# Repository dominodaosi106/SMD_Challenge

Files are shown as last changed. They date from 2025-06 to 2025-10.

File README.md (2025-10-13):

# SMD Challenge Badge

SMD Challenge Badge

# SMD_Challenge

このプロジェクトは、aspro648の[Attiny85Challenge](https://github.com/aspro648/KiCad/tree/master/projects/Attiny/Attiny85Challenge)を基に改変したもので、Creative Commons Attribution-ShareAlike 3.0 United States (CC BY-SA 3.0 US) ライセンスの下で公開されています。  
[https://creativecommons.org/licenses/by-sa/3.0/us/](https://creativecommons.org/licenses/by-sa/3.0/us/)  
また、https://www.tindie.com/products/makersbox/smd-challenge を参考にしています。

## ライセンス
このプロジェクトはCC BY-SA 3.0 USライセンスに従います。  
派生作品も同一ライセンスで公開する必要があります。詳細は[LICENSEファイル](LICENSE.md)をご覧ください。

## 変更点
- LEDの配置を変更し、視認性を向上。
- マイコンをATtiny85からATtiny13Aに変更
- スイッチの追加

## クレジット
- オリジナルプロジェクト: aspro648 Attiny85Challenge (https://github.com/aspro648/KiCad/tree/master/projects/Attiny/Attiny85Challenge)
- 参考製品: Maker's Box SMD Challenge (https://www.tindie.com/products/makersbox/smd-challenge)

---

**SMD Challenge Badge**は、あなたの表面実装部品をはんだ付けスキルを試す究極のキットです！  
ゴマより小さな0603（0.6mm x 0.3mm）のLEDをはんだ付けして、技術と忍耐の限界に挑戦しましょう。  
このキットは、[BOOTH SMD Challenge Badge](https://dominotech.booth.pm/items/6001653)から入手できます。  
上級者向けですが、初心者も大歓迎！さあ、挑戦する覚悟はできていますか？

## 特徴
- **極小サイズの挑戦**: 0603サイズのLEDと抵抗をはんだ付け。
- **達成感抜群**: 完成すれば、胸を張ってつけられるカッコいいバッジが手に入ります！
- **初心者からプロまで**: 上級者向けキットですが、初心者でも挑戦可能。
- **SNSで自慢**: 完成したバッジを[#SMD_Challenge](https://twitter.com/hashtag/SMD_Challenge)で投稿して、世界にあなたのスキルをアピール！

## キット内容

SMD Challenge Badgeのキット内容は以下の通り。

| 部品名 | 詳細 | 数量 | 型番 |
|---|---|---|---|
| **抵抗** | R1: 3216 1kΩ | 1個 | WR12X102 JTL |
| | R2: 2012 1kΩ | 1個 | WR08X102 JTL |
| | R3: 1608 1kΩ | 1個 | WR06X102 JTL |
| | R4: 1005 2.2kΩ | 1個 | WR04X222 JTL |
| | R5: 0603 1kΩ（予備1個） | 1個 + 予備1個 | WR02X102 JAL |
| **LED** | D1: 3216 赤 639nm | 1個 | LTST-C150KRKT |
| | D2: 2012 橙 605nm | 1個 | OSO50805C1C |
| | D3: 1608 黄 591nm | 1個 | OSYL1608 |
| | D4: 1005 緑 525nm | 1個 | OSG50402C1C |
| | D5: 0603 青 470nm（予備1個） | 1個 + 予備1個 | OSB50201C1E |
| **コンデンサ** | C1: 1608 0.1µF | 1個 | GCM188L81H104KA57 |
| **マイコン** | U1: ATtiny13A 8SOIC | 1個 | ATTINY13A-SS7 |
| **スイッチ** | SW1: SSSS811101 または CUS-12TB | 1個 | CUS-12TB |
| **電池ホルダ** | B1: BK-913（スルーホール） | 1個 | BK-913 |
| **電池** | CR2032(テスト用） | 1個 | |
| **バッジ金具** | 貴和製作所 ウラピンNo.101 | 1個 | ウラピンNo.101 |
| **基板** | LBC-3202（直径32mm、FR4） | 1個 | LBC-3202 |
| **糸はんだ** | 0.3mm（約30cm、サンプル用） | 1本 | |
| **説明書** | Manual ver2.3 | 1枚 | |

## **※注意**
- サンプル用の糸はんだは少量です。不足する場合は別途ご用意ください。
- 0603サイズのSMD部品には予備が含まれます。余った場合は…眺めて楽しんで！

## 基板仕様
- **型番**: LBC-3202
- **外形**: 32mm
- **厚み**: 1.6mm
- **材質**: FR4-Standard TG 135-140
- **表面処理**: 有鉛はんだ（RoHS非対応）
- **ピンのピッチ**: T1-T6（マイコン書き込み用）は2.54mm

## 基板設計

SMD Challenge Badgeの基板は、挑戦者の心を掴む設計で作られています！挑戦の舞台裏を覗いてみよう！

- **設計ツール**: EAGLE 6.6.0 Professionalを使用  
(元のAttiny85ChallengeはKiCadで設計されていますが、本プロジェクトではEAGLEで再設計しました。EAGLEの使い慣れた環境とレイアウト最適化のために選択)
- **ガーバーデータ**: [Gerberフォルダ](Gerber)に提供しています。
- **基板サイズ**: 直径32mmの円形で、缶バッジと同じサイズにしました。胸に輝くバッジに最適！
- **パターン幅**: 0.254mm（10mil）で設計
- **設計のこだわり**: 0.254mmパターンで0603部品の安定実装と手作業の限界を両立。円形基板で缶バッジ風の見た目を追求！

※ガーバーデータは[Gerberフォルダ](https://github.com/dominodaosi106/SMD_Challenge/tree/main/Gerber)にあります。SVG版も[SVGフォルダ](https://github.com/dominodaosi106/SMD_Challenge/tree/main/SVG)で公開しています。  
気軽に基板パターンを眺めたい人はSVGをチェック！

 

## 必要な工具
- **はんだごて**: はんだごてはできれば温調できるもの。コテ先は尖ったものがおすすめ  
（例: `HAKKO FX-600`→`T18-C1` , `HAKKO FX-650`→`T34-C08` , `ALIENTEK T80`→`T210-I tip`）  
※コテ先にスズメッキ線を巻きつけて細いコテ先として使う方法もあります。
- **鉛入りはんだ**: 0.3mmの細いものが最適  
（例 : `HOZAN H-712` `HAKKO FS311-03101` `千住金属工業 RMA98SUPER-P3-SN60-0.3`など）
- **フラックス**: 普段使っているものでOK  
（`サンハヤト HB-L15F` `サンハヤト HD-F25` `HOZAN H-722` `HAKKO FS242-10`）
- **高級ピンセット**: 小さな部品をしっかりつかめるもの  
（`HOZAN P-881` `HOZAN P-656` `ENGINEER PT31` `DUMONT TPDN-120-12E`）
- **拡大鏡または実体顕微鏡**: 作業が格段に楽になります。なければ100円ショップのルーペでも代用可能！  
（`OLYMPUS SZ61` `HOZAN L-51` `ESCHENBACH 1646-40` `マイクロネット YS05T`）
- **たくさんの忍耐、持続力、そして前向きな姿勢！**　失敗しても大丈夫、チャレンジを楽しもう！

## 組み立てガイド
詳細な組み立て手順は、以下のリンクを参照してください：
- [組み立て説明書](Manual/SMD_Challenge_Badge_Manual_ver2.3.pdf)

動作確認動画  
動作動画 (https://www.youtube.com/watch?v=hwRiR8ovcfM)

### 製作のポイント
1. **表面（TOP）から開始**: 裏面から始めると難易度が跳ね上がります！
2. **大きい部品から**: 3216→2012→1608→1005→0603の順で。大きいSMD部品から始めるとモチベーションを保ちやすいです。
3. **LEDの極性に注意**: 逆向きだと光りません（50:50の運試し！）。カソードの向きは説明書を参考に。
4. **LEDの取り扱い**: 樹脂部をピンセットで強く押さえないで。傷や断線で点灯不良の原因に。
5. **スイッチ（SW1）**: 熱に注意し慎重にはんだ付け。
6. **パスコン（C1）**: マイコンより先にはんだ付け。
7. **マイコン（U1）**: 向きを確認し正確に実装。
8. **裏面実装**: 電池ホルダ（B1）とウラピンNo.101を向きに注意してはんだ付け。  
ウラピンはピンを開き、基板裏面を上にして針を右側、止め金具を左側にセット！
9. **フラックス除去**: フラックスクリーナー（例: `FL-500` `FL-L15`）やイソプロピルアルコールで洗浄して完成！

※SMD部品の開封はキット付属の薄い袋の中で行うと、紛失リスクを少し軽減できます。

安全に気をつけて、はんだ付けの「狂人」への道を突き進もう！

## 完成したら
- **SNSで投稿**: Twitterやその他のSNSで[#SMD_Challenge](https://twitter.com/intent/tweet?hashtags=SMD_Challenge)を付けて投稿！  
成功も失敗も、コミュニティでシェアしよう！
- **挑戦の証**: 完成したバッジを胸に、はんだ付けの「狂人」として誇示！

---

## [バッジを完成させた人物の一覧](COMPLETERS.md)
※@dominodaosi106 が不定期で更新しています。

---

## 注意事項
- **電池の向き**: CR2032はマイナス面が基板側。
- **RoHS非対応**: 鉛入りはんだを使用。取り扱いに注意。
- **0603のLEDは非常に脆い**: 完成後はUVレジンやケースで保護を。

推奨ケース
- [明邦化学工業 ラウンドケース S 5段 クリア](https://meihokagaku.co.jp/?p=2736)
- [ラウンドケースS　フタ](https://meihokagaku.co.jp/?p=2709)
- 専用のケースを設計しました。[STLデータはこちら](3D/40mm_round_cap.stl)

## ファームウェア
このキットのAVRマイコンはHIDaspxを使って書き込みしています。  
AtmelStudio7を使ってプログラミングしてコンパイルしています。  
AVRマイコンのファームウェアなどは[Firmware](Firmware)にあります。

## オリジナルとの改良点

SMD Challenge Badgeは、[Hackaday.ioの"An Unfortunate SMD Project"](https://hackaday.io/project/25265-an-unfortunate-smd-project)に敬意を表しつつ、使いやすさと耐久性を追求して進化させました！以下は、本家との主な違い：

- **LED配置を逆転**: 壊れやすい0603サイズのLEDを一番安全な場所に移動。極小パーツを守るための戦略的配置！
- **基板サイズの拡大**: 本家よりゆったり設計で、作業スペースを確保。はんだ付けのストレスが少し軽減！
- **電源スイッチの追加**: 本家にはないスライドスイッチを搭載。電源のON/OFFが簡単で、バッジの輝きをコントロール！
- **缶バッジ風金具**: 本家のピンバッジから、缶バッジと同じような金具へ変更。装着感も個性もアップ！
- **マイコンの変更**: 本家のATtiny85からATtiny13Aに変更。ATtiny13Aは低コストで同等のパフォーマンスを提供し、入手性がとても良いので採用。
- **電池ホルダをスルーホールに**: SMDの電池金具は剥がれやすいので、スルーホール型に変更。ガッチリ固定で頑丈に！

これらの改良で、挑戦のスリルはそのままに、初心者から上級者まで楽しめるキットに仕上げました！

## サポート
質問やサポートが必要な場合は、[dominodaosi106](https://twitter.com/dominodaosi106)か説明書のメールアドレスからお問い合わせください。  
また、コミュニティで[#SMD_Challenge](https://twitter.com/hashtag/SMD_Challenge)をチェックして、他の挑戦者と交流しましょう！

## よくある質問
### **部品をなくした！**
- 0603は飛んでいきがち。0603LEDは秋月へ。型番:OSB50201C1E(販売コード:118279)
- 0603は飛んでいきがち。0603抵抗はDigiKeyへ。型番:[WR02X102](https://www.digikey.jp/ja/products/detail/walsin-technology-corporation/WR02X102-JAL/13238943)※[マルツ](https://www.marutsu.co.jp/pc/i/35771794/)でも入手可能
- LEDが光らない？: 極性ミスはSMDの洗礼。説明書やテスターでカソードを確認！
- おすすめのはんだごては？: HAKKO FX-600にT18-C1やT18-ISがオススメ!
- **実体顕微鏡がない！**: 100円ショップのルーペでも代用可。根気でカバー！

**はんだごてを握り、SMDの極小世界に挑もう！**  
0603を制覇すれば、あなたも「はんだ付けの狂人」の仲間入り！どこまでできるか、挑戦しよう！

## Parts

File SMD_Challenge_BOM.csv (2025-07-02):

部品名 | 詳細 | 数量 | 型番 | 単価
抵抗 | R1: 3216 1kΩ | 1個 | WR12X102 JTL | 14.38
抵抗 | R2: 2012 1kΩ | 1個 | WR08X102 JTL | 10
抵抗 | R3: 1608 1kΩ | 1個 | WR06X102 JTL | 9.8
抵抗 | R4: 1005 2.2kΩ | 1個 | WR04X222 JTL | 9
抵抗 | R5: 0603 1kΩ（予備1個） | 1個 + 予備1個 | WR02X102 JAL | 20
LED | D1: 3216 赤 639nm | 1個 | LTST-C150KRKT | 1.084
LED | D2: 2012 橙 605nm | 1個 | OSO50805C1C | 0.75
LED | D3: 1608 黄 591nm | 1個 | OSYL1608 | 0.504
LED | D4: 1005 緑 525nm | 1個 | OSG50402C1C | 0.404
LED | D5: 0603 青 470nm（予備1個） | 1個 + 予備1個 | OSB50201C1E | 1.816
コンデンサ | C1: 1608 0.1µF | 1個 | GCM188L81H104KA57 | 2
マイコン | U1: ATtiny13A 8SOIC | 1個 | ATTINY13A-SS7 | 102.6
スイッチ | SW1: SSSS811101 または CUS-12TB | 1個 | CUS-12TB | 127.88
電池ホルダ | B1: BK-913（スルーホール） | 1個 | BK-913 | 66.88
電池 | CR2032(テスト用） | 1個 |  | 40
バッジ金具 | 貴和製作所 ウラピンNo.101 | 1個 | ウラピンNo.101 | 17
基板 | LBC-3202（直径32mm、FR4） | 1個 | LBC-3202 | 160
糸はんだ | 0.3mm（約30cm、サンプル用） | 1本
説明書 | Manual ver2.3 | 1枚 |  | 20
梱包材 |  |  |  | 40
 |  |  |  | 644.098

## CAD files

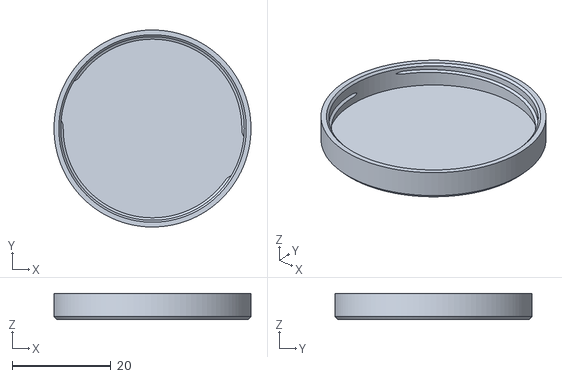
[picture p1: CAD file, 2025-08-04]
3D/40mm_round_cap.stl
40.0 x 40.0 x 5.30

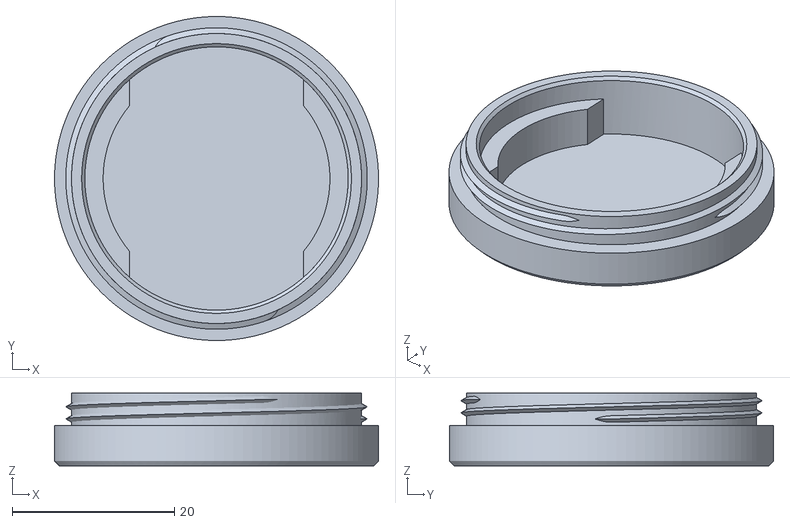
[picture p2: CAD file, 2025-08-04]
3D/40mm_round_case.stl
40.0 x 40.0 x 9.00

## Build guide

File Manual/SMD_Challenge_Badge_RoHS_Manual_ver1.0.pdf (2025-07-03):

# SMD Challenge Badge RoHS Edition

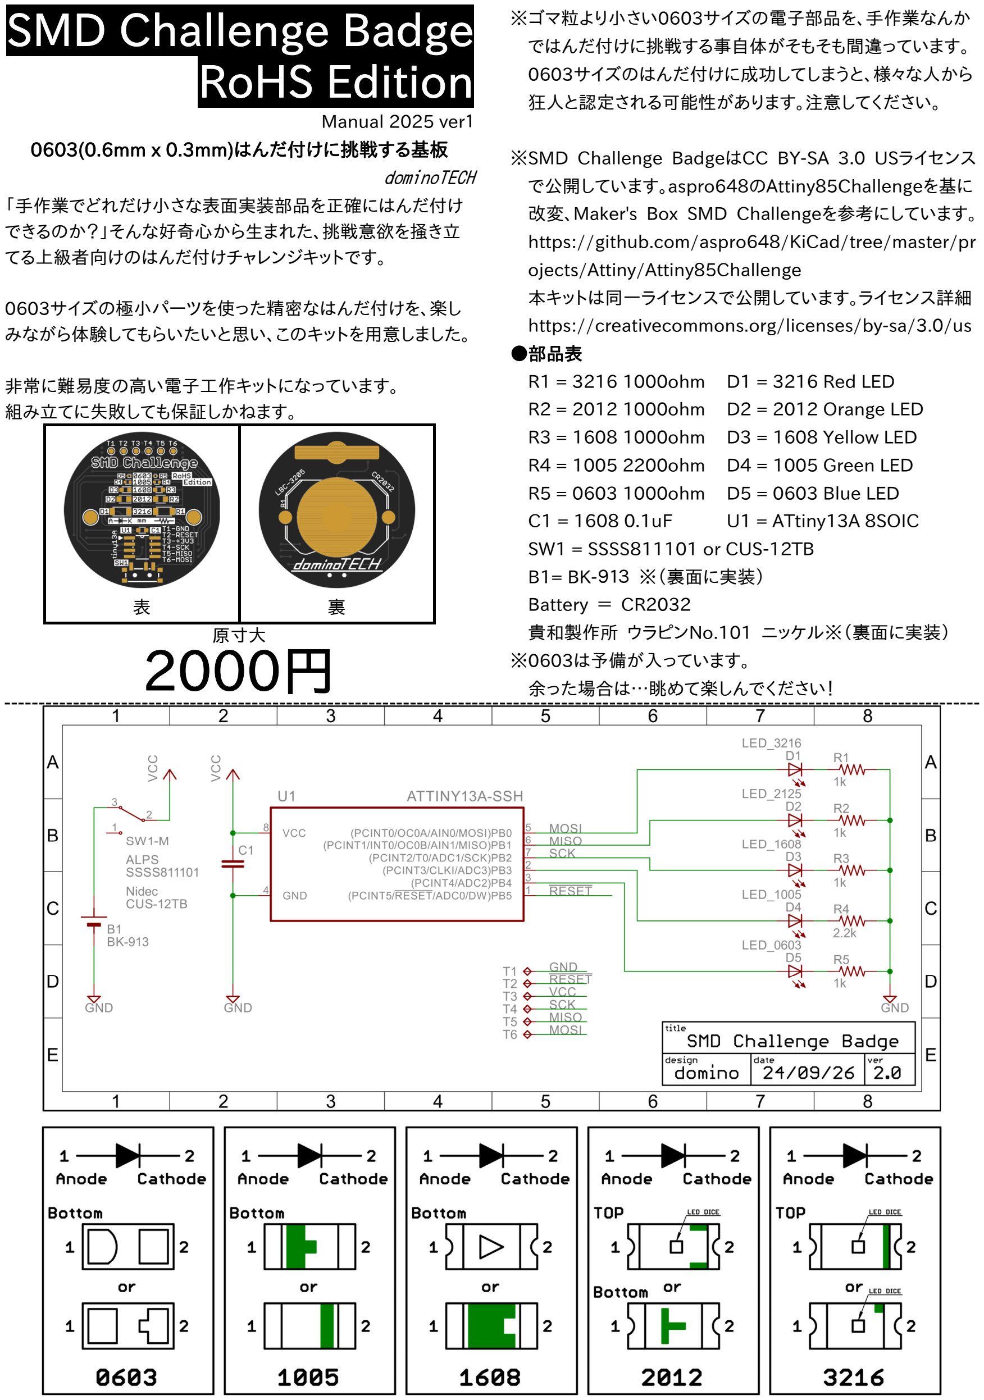
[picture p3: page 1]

Manual 2025 ver１
0603(0.6mm x 0.3mm)はんだ付けに挑戦する基板
dominoTECH
「手作業でどれだけ小さな表面実装部品を正確にはんだ付け できるのか？」そんな好奇心から生まれた、挑戦意欲を掻き立 てる上級者向けのはんだ付けチャレンジキットです。

0603サイズの極小パーツを使った精密なはんだ付けを、楽し みながら体験してもらいたいと思い、このキットを用意しました。

非常に難易度の高い電子工作キットになっています。
組み立てに失敗しても保証しかねます。
表 | 裏
原寸大
2000円

※ゴマ粒より小さい0603サイズの電子部品を、手作業なんか ではんだ付けに挑戦する事自体がそもそも間違っています。 0603サイズのはんだ付けに成功してしまうと、様々な人から 狂人と認定される可能性があります。注意してください。

※SMD Challenge BadgeはCC BY-SA 3.0 USライセンス で公開しています。aspro648のAttiny85Challengeを基に 改変、Maker's Box SMD Challengeを参考にしています。 https://github.com/aspro648/KiCad/tree/master/projects/Attiny/Attiny85Challenge 本キットは同一ライセンスで公開しています。ライセンス詳細 https://creativecommons.org/licenses/by-sa/3.0/us ●部品表
R1 = 3216 1000ohm D1 = 3216 Red LED
R2 = 2012 1000ohm D2 = 2012 Orange LED
R3 = 1608 1000ohm D3 = 1608 Yellow LED R4 = 1005 2200ohm D4 = 1005 Green LED R5 = 0603 1000ohm D5 = 0603 Blue LED C1 = 1608 0.1uF U1 = ATtiny13A 8SOIC SW1 = SSSS811101 or CUS-12TB
B1= BK-９１３ ※（裏面に実装）
Battery ＝ CR2032
貴和製作所 ウラピンNo.101 ニッケル※（裏面に実装） ※0603は予備が入っています。
余った場合は…眺めて楽しんでください！

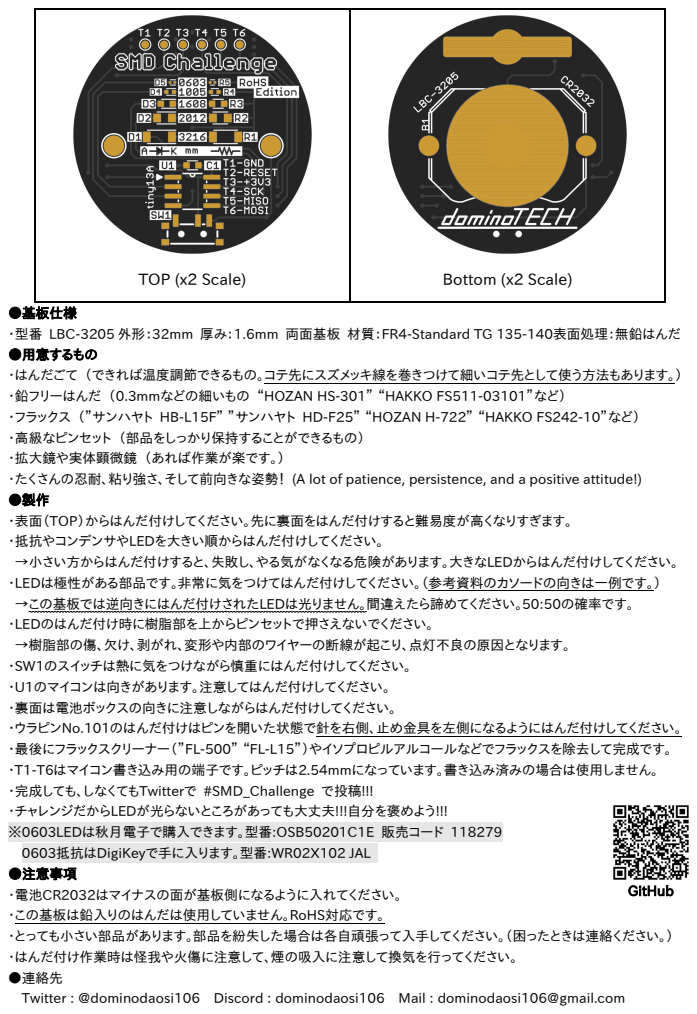
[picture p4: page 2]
TOP (x2 Scale); Bottom (x2 Scale); GitHub

●基板仕様
・型番 LBC-3205 外形：32mm 厚み：1.6mm 両面基板 材質：FR4-Standard TG 135-140表面処理：無鉛はんだ
●用意するもの
・はんだごて （できれば温度調節できるもの。コテ先にスズメッキ線を巻きつけて細いコテ先として使う方法もあります。）
・鉛フリーはんだ （0.3mmなどの細いもの “HOZAN HS-301” “HAKKO FS511-03101”など）
・フラックス （”サンハヤト HB-L15F” ”サンハヤト HD-F25” “HOZAN H-722” “HAKKO FS242-10”など）
・高級なピンセット （部品をしっかり保持することができるもの）
・拡大鏡や実体顕微鏡 （あれば作業が楽です。）
・たくさんの忍耐、粘り強さ、そして前向きな姿勢！ (A lot of patience, persistence, and a positive attitude!)
・表面（TOP）からはんだ付けしてください。先に裏面をはんだ付けすると難易度が高くなりすぎます。
・抵抗やコンデンサやLEDを大きい順からはんだ付けしてください。
→小さい方からはんだ付けすると、失敗し、やる気がなくなる危険があります。大きなLEDからはんだ付けしてください。
・LEDは極性がある部品です。非常に気をつけてはんだ付けしてください。（参考資料のカソードの向きは一例です。）
→この基板では逆向きにはんだ付けされたLEDは光りません。間違えたら諦めてください。50:50の確率です。
・LEDのはんだ付け時に樹脂部を上からピンセットで押さえないでください。
→樹脂部の傷、欠け、剥がれ、変形や内部のワイヤーの断線が起こり、点灯不良の原因となります。
・SW1のスイッチは熱に気をつけながら慎重にはんだ付けしてください。
・U1のマイコンは向きがあります。注意してはんだ付けしてください。
・裏面は電池ボックスの向きに注意しながらはんだ付けしてください。
・ウラピンNo.101のはんだ付けはピンを開いた状態で針を右側、止め金具を左側になるようにはんだ付けしてください。
・最後にフラックスクリーナー（”FL-500” “FL-L15”）やイソプロピルアルコールなどでフラックスを除去して完成です。
・T1-T6はマイコン書き込み用の端子です。ピッチは2.54mmになっています。書き込み済みの場合は使用しません。
・完成しても、しなくてもTwitterで #SMD_Challenge で投稿!!!
・チャレンジだからLEDが光らないところがあっても大丈夫!!!自分を褒めよう!!!
※0603LEDは秋月電子で購入できます。型番:OSB50201C1E 販売コード 118279
0603抵抗はDigiKeyで手に入ります。型番:WR02X102 JAL
●注意事項
・電池CR2032はマイナスの面が基板側になるように入れてください。
・この基板は鉛入りのはんだは使用していません。RoHS対応です。
・とっても小さい部品があります。部品を紛失した場合は各自頑張って入手してください。（困ったときは連絡ください。）
・はんだ付け作業時は怪我や火傷に注意して、煙の吸入に注意して換気を行ってください。
●連絡先
Twitter : @dominodaosi106 Discord : dominodaosi106 Mail : dominodaosi106@gmail.com

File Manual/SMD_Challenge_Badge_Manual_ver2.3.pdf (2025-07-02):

# SMD Challenge Badge

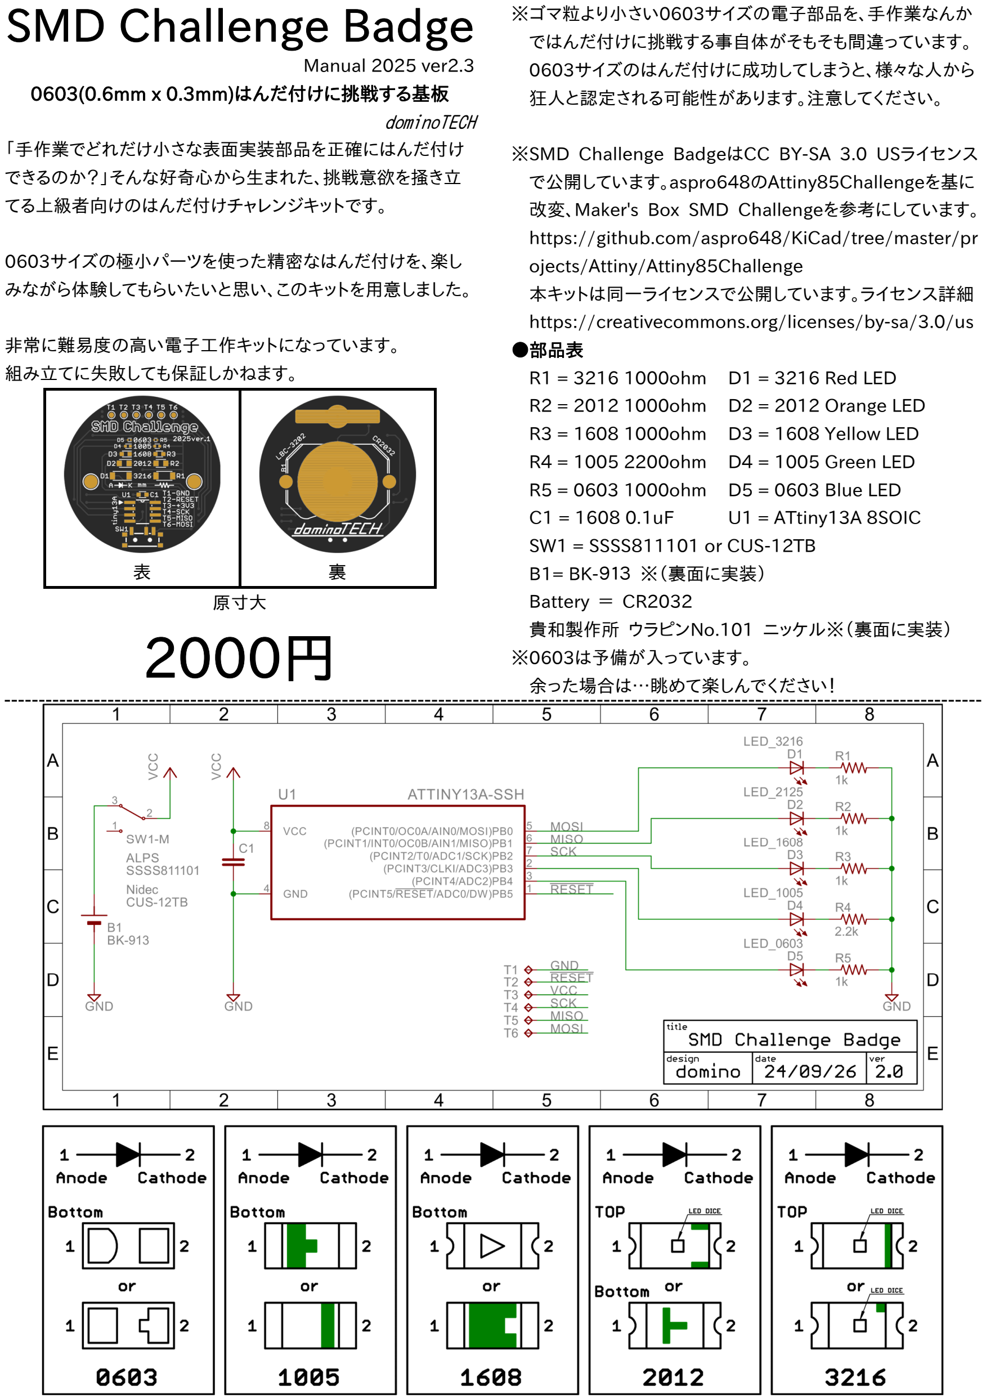
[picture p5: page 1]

Manual 2025 ver2.3
0603(0.6mm x 0.3mm)はんだ付けに挑戦する基板
dominoTECH
「手作業でどれだけ小さな表面実装部品を正確にはんだ付け できるのか？」そんな好奇心から生まれた、挑戦意欲を掻き立 てる上級者向けのはんだ付けチャレンジキットです。

0603サイズの極小パーツを使った精密なはんだ付けを、楽し みながら体験してもらいたいと思い、このキットを用意しました。

非常に難易度の高い電子工作キットになっています。
組み立てに失敗しても保証しかねます。
表 | 裏
原寸大
2000円

※ゴマ粒より小さい0603サイズの電子部品を、手作業なんか ではんだ付けに挑戦する事自体がそもそも間違っています。 0603サイズのはんだ付けに成功してしまうと、様々な人から 狂人と認定される可能性があります。注意してください。

※SMD Challenge BadgeはCC BY-SA 3.0 USライセンス で公開しています。aspro648のAttiny85Challengeを基に 改変、Maker's Box SMD Challengeを参考にしています。 https://github.com/aspro648/KiCad/tree/master/projects/Attiny/Attiny85Challenge 本キットは同一ライセンスで公開しています。ライセンス詳細 https://creativecommons.org/licenses/by-sa/3.0/us ●部品表
R1 = 3216 1000ohm D1 = 3216 Red LED
R2 = 2012 1000ohm D2 = 2012 Orange LED
R3 = 1608 1000ohm D3 = 1608 Yellow LED R4 = 1005 2200ohm D4 = 1005 Green LED R5 = 0603 1000ohm D5 = 0603 Blue LED C1 = 1608 0.1uF U1 = ATtiny13A 8SOIC SW1 = SSSS811101 or CUS-12TB
B1= BK-９１３ ※（裏面に実装）
Battery ＝ CR2032
貴和製作所 ウラピンNo.101 ニッケル※（裏面に実装） ※0603は予備が入っています。
余った場合は…眺めて楽しんでください！

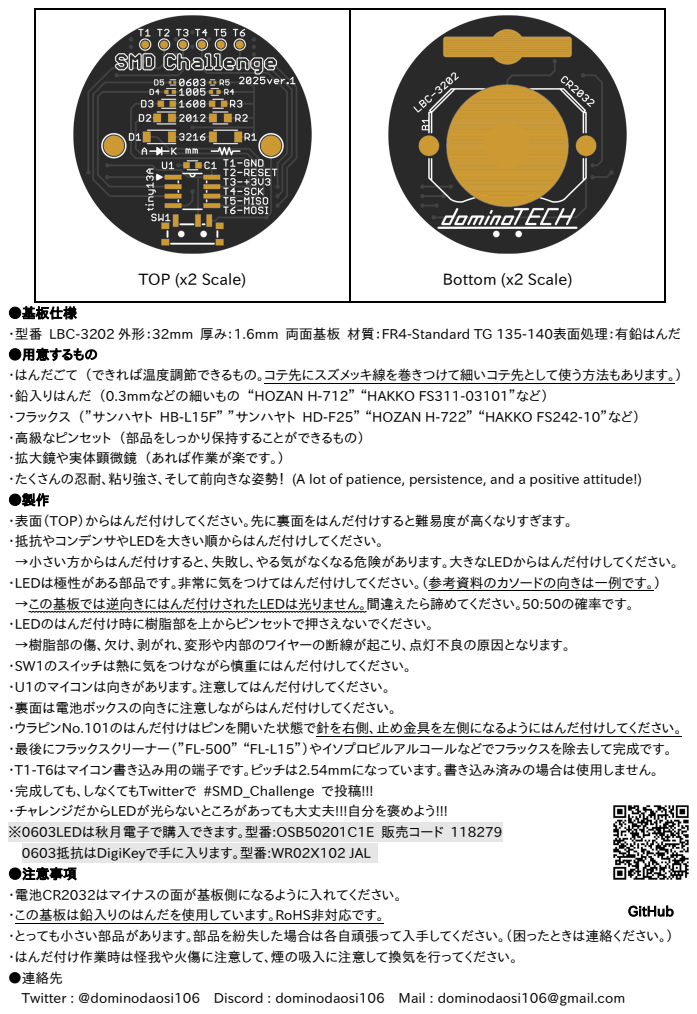
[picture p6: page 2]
TOP (x2 Scale); Bottom (x2 Scale); GitHub

●基板仕様
・型番 LBC-3202 外形：32mm 厚み：1.6mm 両面基板 材質：FR4-Standard TG 135-140表面処理：有鉛はんだ
●用意するもの
・はんだごて （できれば温度調節できるもの。コテ先にスズメッキ線を巻きつけて細いコテ先として使う方法もあります。）
・鉛入りはんだ （0.3mmなどの細いもの “HOZAN H-712” “HAKKO FS311-03101”など）
・フラックス （”サンハヤト HB-L15F” ”サンハヤト HD-F25” “HOZAN H-722” “HAKKO FS242-10”など）
・高級なピンセット （部品をしっかり保持することができるもの）
・拡大鏡や実体顕微鏡 （あれば作業が楽です。）
・たくさんの忍耐、粘り強さ、そして前向きな姿勢！ (A lot of patience, persistence, and a positive attitude!)
・表面（TOP）からはんだ付けしてください。先に裏面をはんだ付けすると難易度が高くなりすぎます。
・抵抗やコンデンサやLEDを大きい順からはんだ付けしてください。
→小さい方からはんだ付けすると、失敗し、やる気がなくなる危険があります。大きなLEDからはんだ付けしてください。
・LEDは極性がある部品です。非常に気をつけてはんだ付けしてください。（参考資料のカソードの向きは一例です。）
→この基板では逆向きにはんだ付けされたLEDは光りません。間違えたら諦めてください。50:50の確率です。
・LEDのはんだ付け時に樹脂部を上からピンセットで押さえないでください。
→樹脂部の傷、欠け、剥がれ、変形や内部のワイヤーの断線が起こり、点灯不良の原因となります。
・SW1のスイッチは熱に気をつけながら慎重にはんだ付けしてください。
・U1のマイコンは向きがあります。注意してはんだ付けしてください。
・裏面は電池ボックスの向きに注意しながらはんだ付けしてください。
・ウラピンNo.101のはんだ付けはピンを開いた状態で針を右側、止め金具を左側になるようにはんだ付けしてください。
・最後にフラックスクリーナー（”FL-500” “FL-L15”）やイソプロピルアルコールなどでフラックスを除去して完成です。
・T1-T6はマイコン書き込み用の端子です。ピッチは2.54mmになっています。書き込み済みの場合は使用しません。
・完成しても、しなくてもTwitterで #SMD_Challenge で投稿!!!
・チャレンジだからLEDが光らないところがあっても大丈夫!!!自分を褒めよう!!!
※0603LEDは秋月電子で購入できます。型番:OSB50201C1E 販売コード 118279
0603抵抗はDigiKeyで手に入ります。型番:WR02X102 JAL
●注意事項
・電池CR2032はマイナスの面が基板側になるように入れてください。
・この基板は鉛入りのはんだを使用しています。RoHS非対応です。
・とっても小さい部品があります。部品を紛失した場合は各自頑張って入手してください。（困ったときは連絡ください。）
・はんだ付け作業時は怪我や火傷に注意して、煙の吸入に注意して換気を行ってください。
●連絡先
Twitter : @dominodaosi106 Discord : dominodaosi106 Mail : dominodaosi106@gmail.com

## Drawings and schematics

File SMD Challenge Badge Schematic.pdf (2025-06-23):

1 | 2 | 3 | 4 | 5 | 6 | 7 | 8

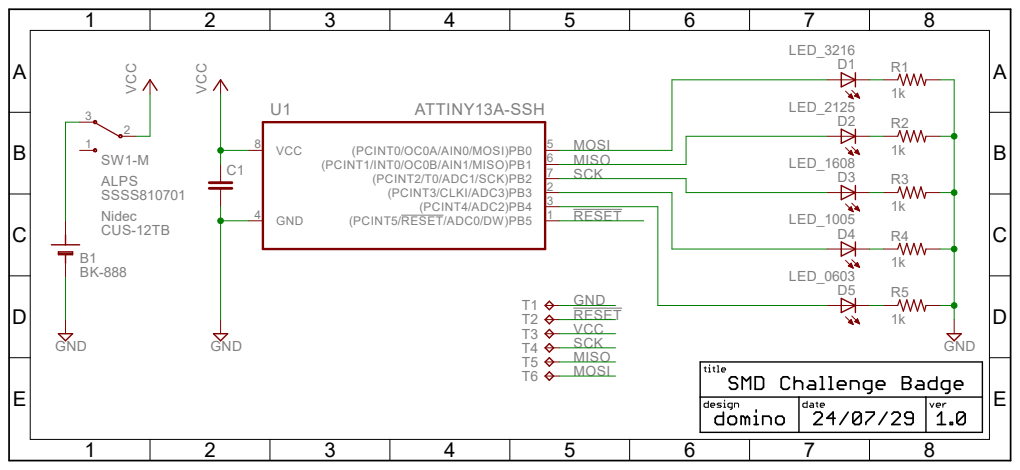
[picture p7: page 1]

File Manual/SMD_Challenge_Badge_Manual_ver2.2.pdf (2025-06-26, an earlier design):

# SMD Challenge Badge

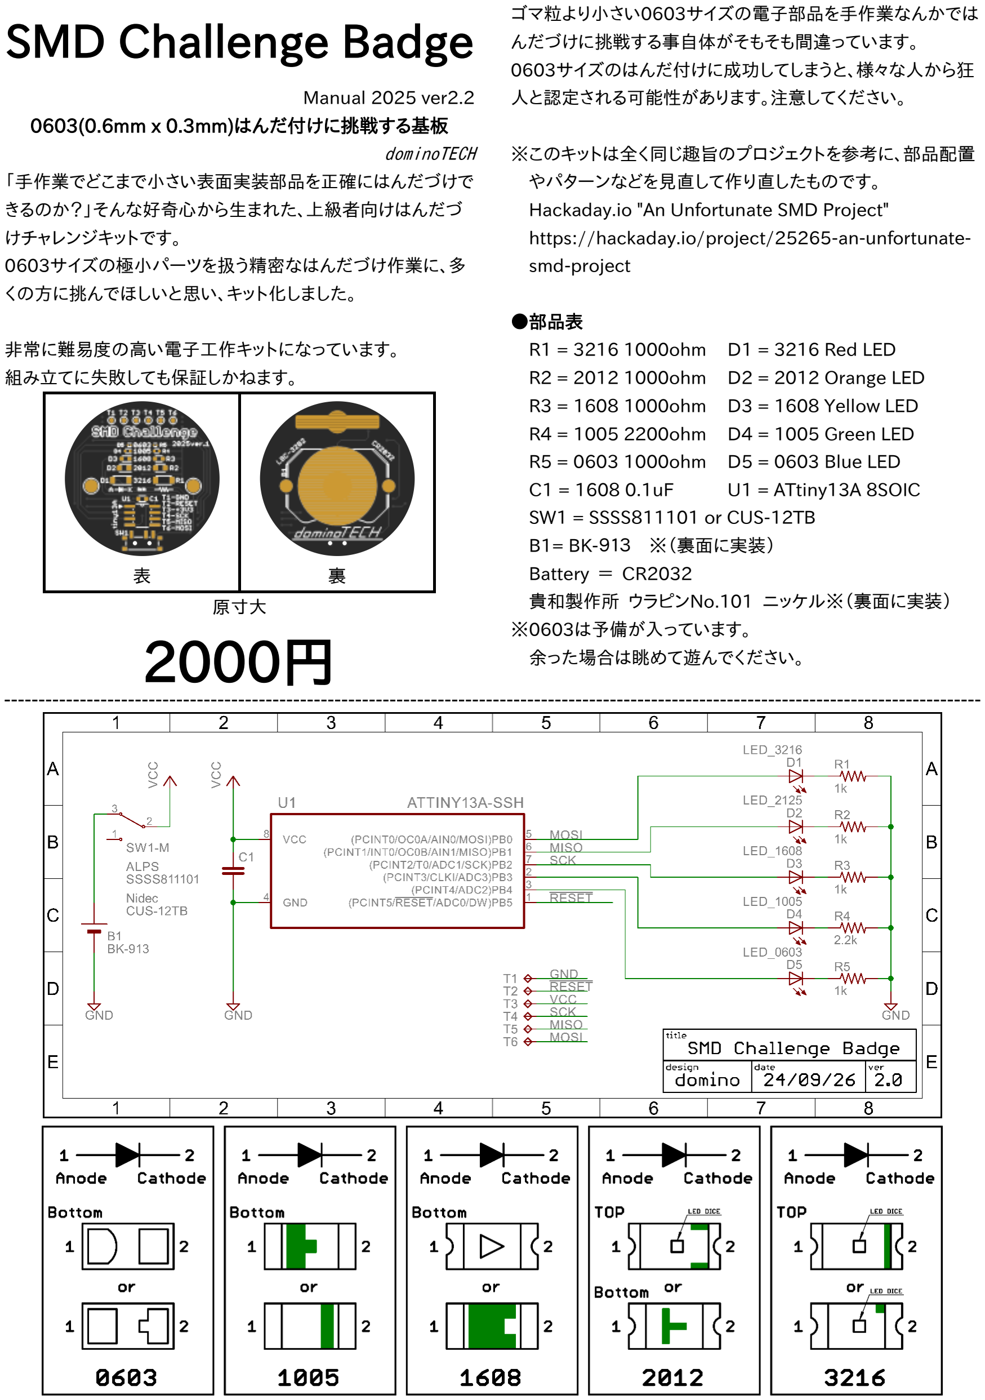
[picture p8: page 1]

Manual 2025 ver2.2
0603(0.6mm x 0.3mm)はんだ付けに挑戦する基板 dominoTECH
「手作業でどこまで小さい表面実装部品を正確にはんだづけで きるのか？」そんな好奇心から生まれた、上級者向けはんだづ けチャレンジキットです。
0603サイズの極小パーツを扱う精密なはんだづけ作業に、多 くの方に挑んでほしいと思い、キット化しました。

非常に難易度の高い電子工作キットになっています。
組み立てに失敗しても保証しかねます。
表 | 裏
原寸大
2000円

ゴマ粒より小さい0603サイズの電子部品を手作業なんかでは んだづけに挑戦する事自体がそもそも間違っています。
0603サイズのはんだ付けに成功してしまうと、様々な人から狂 人と認定される可能性があります。注意してください。

※このキットは全く同じ趣旨のプロジェクトを参考に、部品配置 やパターンなどを見直して作り直したものです。
Hackaday.io "An Unfortunate SMD Project" https://hackaday.io/project/25265-an-unfortunate-smd-project

●部品表
R1 = 3216 1000ohm D1 = 3216 Red LED R2 = 2012 1000ohm D2 = 2012 Orange LED R3 = 1608 1000ohm D3 = 1608 Yellow LED R4 = 1005 2200ohm D4 = 1005 Green LED R5 = 0603 1000ohm D5 = 0603 Blue LED C1 = 1608 0.1uF U1 = ATtiny13A 8SOIC SW1 = SSSS811101 or CUS-12TB
B1= BK-９１３ ※（裏面に実装）
Battery ＝ CR2032
貴和製作所 ウラピンNo.101 ニッケル※（裏面に実装） ※0603は予備が入っています。
余った場合は眺めて遊んでください。

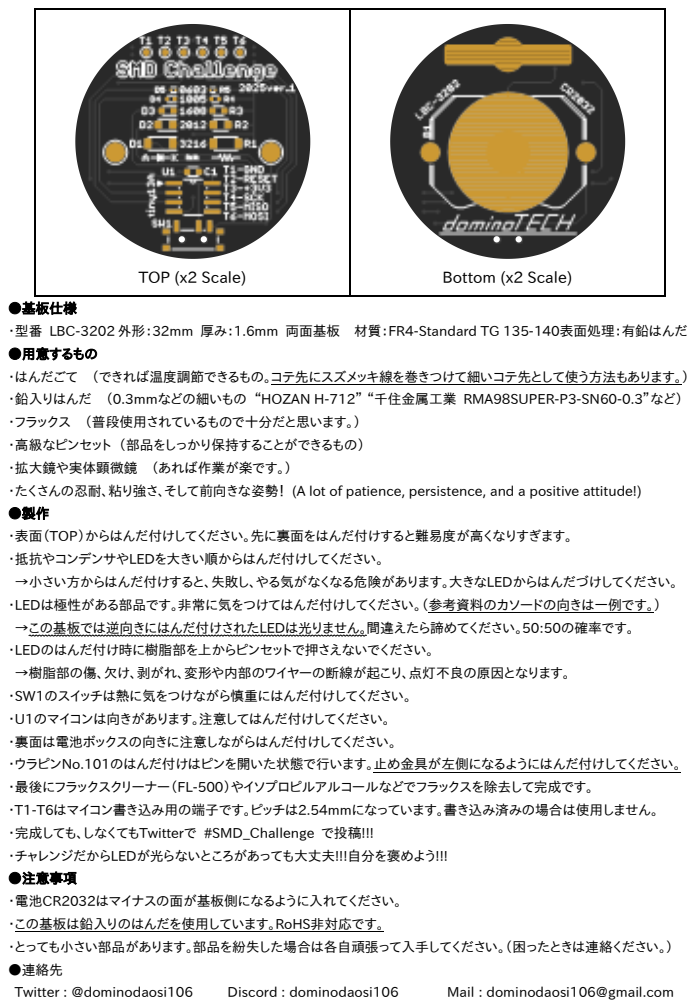
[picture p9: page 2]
TOP (x2 Scale); Bottom (x2 Scale); Twitter : @dominodaosi106; Discord : dominodaosi106; Mail : dominodaosi106@gmail.com

●基板仕様
・型番 LBC-3202 外形：32mm 厚み：1.6mm 両面基板 材質：FR4-Standard TG 135-140表面処理：有鉛はんだ
●用意するもの
・はんだごて （できれば温度調節できるもの。コテ先にスズメッキ線を巻きつけて細いコテ先として使う方法もあります。）
・鉛入りはんだ （0.3mmなどの細いもの “HOZAN H-712” “千住金属工業 RMA98SUPER-P3-SN60-0.3”など）
・フラックス （普段使用されているもので十分だと思います。）
・高級なピンセット （部品をしっかり保持することができるもの）
・拡大鏡や実体顕微鏡 （あれば作業が楽です。）
・たくさんの忍耐、粘り強さ、そして前向きな姿勢！ (A lot of patience, persistence, and a positive attitude!)
・表面（TOP）からはんだ付けしてください。先に裏面をはんだ付けすると難易度が高くなりすぎます。
・抵抗やコンデンサやLEDを大きい順からはんだ付けしてください。
→小さい方からはんだ付けすると、失敗し、やる気がなくなる危険があります。大きなLEDからはんだづけしてください。
・LEDは極性がある部品です。非常に気をつけてはんだ付けしてください。（参考資料のカソードの向きは一例です。）
→この基板では逆向きにはんだ付けされたLEDは光りません。間違えたら諦めてください。50:50の確率です。
・LEDのはんだ付け時に樹脂部を上からピンセットで押さえないでください。
→樹脂部の傷、欠け、剥がれ、変形や内部のワイヤーの断線が起こり、点灯不良の原因となります。
・SW1のスイッチは熱に気をつけながら慎重にはんだ付けしてください。
・U1のマイコンは向きがあります。注意してはんだ付けしてください。
・裏面は電池ボックスの向きに注意しながらはんだ付けしてください。
・ウラピンNo.101のはんだ付けはピンを開いた状態で行います。止め金具が左側になるようにはんだ付けしてください。
・最後にフラックスクリーナー（FL-500）やイソプロピルアルコールなどでフラックスを除去して完成です。
・T1-T6はマイコン書き込み用の端子です。ピッチは2.54mmになっています。書き込み済みの場合は使用しません。
・完成しても、しなくてもTwitterで #SMD_Challenge で投稿!!!
・チャレンジだからLEDが光らないところがあっても大丈夫!!!自分を褒めよう!!!
●注意事項
・電池CR2032はマイナスの面が基板側になるように入れてください。
・この基板は鉛入りのはんだを使用しています。RoHS非対応です。
・とっても小さい部品があります。部品を紛失した場合は各自頑張って入手してください。（困ったときは連絡ください。）
●連絡先

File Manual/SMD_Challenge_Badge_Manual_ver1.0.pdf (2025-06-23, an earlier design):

# SMD Challenge Badge

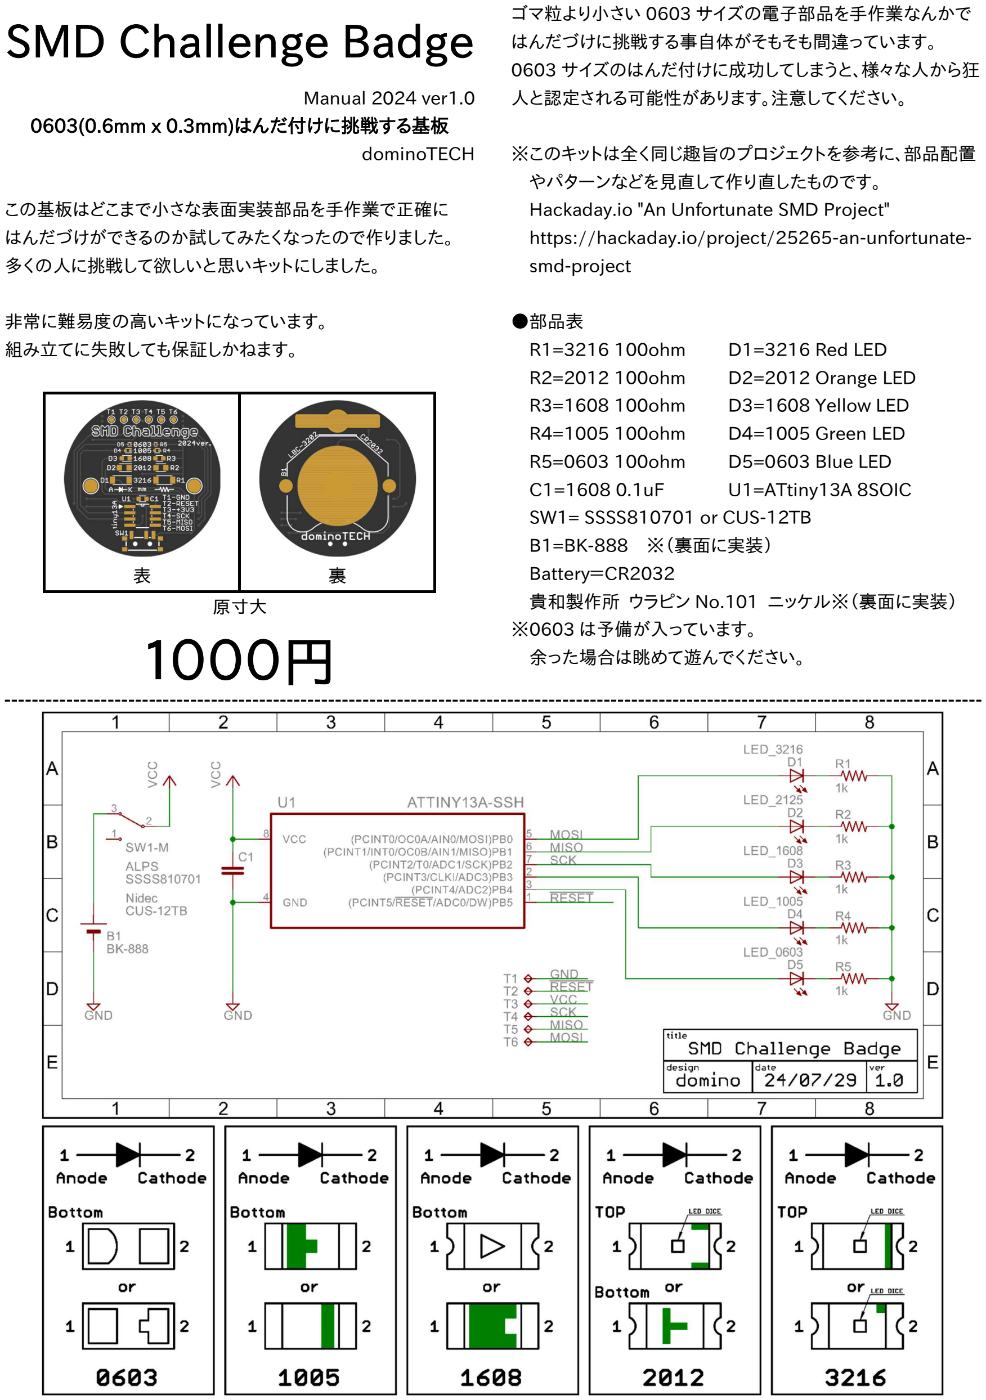
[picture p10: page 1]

Manual 2024 ver1.0
0603(0.6mm x 0.3mm)はんだ付けに挑戦する基板 dominoTECH

この基板はどこまで小さな表面実装部品を手作業で正確に はんだづけができるのか試してみたくなったので作りました。 多くの人に挑戦して欲しいと思いキットにしました。

非常に難易度の高いキットになっています。
組み立てに失敗しても保証しかねます。
表 | 裏
原寸大
１０００円

ゴマ粒より小さい 0603 サイズの電子部品を手作業なんかで はんだづけに挑戦する事自体がそもそも間違っています。 0603 サイズのはんだ付けに成功してしまうと、様々な人から狂 人と認定される可能性があります。注意してください。

※このキットは全く同じ趣旨のプロジェクトを参考に、部品配置 やパターンなどを見直して作り直したものです。
Hackaday.io "An Unfortunate SMD Project" https://hackaday.io/project/25265-an-unfortunate-smd-project

●部品表
R1=3216 100ohm | D1=3216 Red LED
R2=2012 100ohm | D2=2012 Orange LED
R3=1608 100ohm | D3=1608 Yellow LED
R4=1005 100ohm | D4=1005 Green LED
R5=0603 100ohm | D5=0603 Blue LED
C1=1608 0.1uF | U1=ATtiny13A 8SOIC
SW1= SSSS810701 or CUS-12TB
B1=BK-888 ※（裏面に実装）
Battery＝CR2032
貴和製作所 ウラピン No.101 ニッケル※（裏面に実装） ※0603 は予備が入っています。
余った場合は眺めて遊んでください。

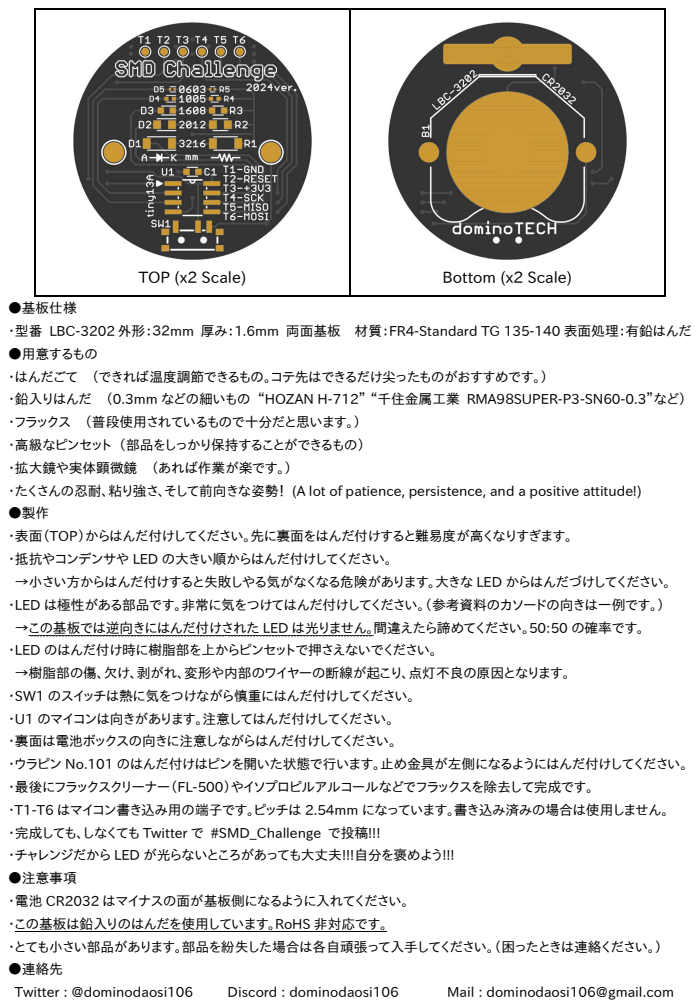
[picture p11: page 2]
TOP (x2 Scale); Bottom (x2 Scale); Twitter : @dominodaosi106; Discord : dominodaosi106; Mail : dominodaosi106@gmail.com

●基板仕様
・型番 LBC-3202 外形：３２mm 厚み：1.6mm 両面基板 材質：FR4-Standard TG 135-140 表面処理：有鉛はんだ
●用意するもの
・はんだごて （できれば温度調節できるもの。コテ先はできるだけ尖ったものがおすすめです。）
・鉛入りはんだ （0.3mm などの細いもの “HOZAN H-712” “千住金属工業 RMA98SUPER-P3-SN60-0.3”など）
・フラックス （普段使用されているもので十分だと思います。）
・高級なピンセット （部品をしっかり保持することができるもの）
・拡大鏡や実体顕微鏡 （あれば作業が楽です。）
・たくさんの忍耐、粘り強さ、そして前向きな姿勢！ (A lot of patience, persistence, and a positive attitude!)
・表面（TOP）からはんだ付けしてください。先に裏面をはんだ付けすると難易度が高くなりすぎます。
・抵抗やコンデンサや LED の大きい順からはんだ付けしてください。
→小さい方からはんだ付けすると失敗しやる気がなくなる危険があります。大きな LED からはんだづけしてください。
・LED は極性がある部品です。非常に気をつけてはんだ付けしてください。（参考資料のカソードの向きは一例です。）
→この基板では逆向きにはんだ付けされた LED は光りません。間違えたら諦めてください。50:50 の確率です。
・LED のはんだ付け時に樹脂部を上からピンセットで押さえないでください。
→樹脂部の傷、欠け、剥がれ、変形や内部のワイヤーの断線が起こり、点灯不良の原因となります。
・SW1 のスイッチは熱に気をつけながら慎重にはんだ付けしてください。
・U1 のマイコンは向きがあります。注意してはんだ付けしてください。
・裏面は電池ボックスの向きに注意しながらはんだ付けしてください。
・ウラピン No.101 のはんだ付けはピンを開いた状態で行います。止め金具が左側になるようにはんだ付けしてください。
・最後にフラックスクリーナー（FL-500）やイソプロピルアルコールなどでフラックスを除去して完成です。
・T1-T6 はマイコン書き込み用の端子です。ピッチは 2.54mm になっています。書き込み済みの場合は使用しません。
・完成しても、しなくても Twitter で #SMD_Challenge で投稿!!!
・チャレンジだから LED が光らないところがあっても大丈夫!!!自分を褒めよう!!!
●注意事項
・電池 CR2032 はマイナスの面が基板側になるように入れてください。
・この基板は鉛入りのはんだを使用しています。RoHS 非対応です。
・とても小さい部品があります。部品を紛失した場合は各自頑張って入手してください。（困ったときは連絡ください。）
●連絡先

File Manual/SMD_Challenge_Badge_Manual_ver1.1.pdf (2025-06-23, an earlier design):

# SMD Challenge Badge

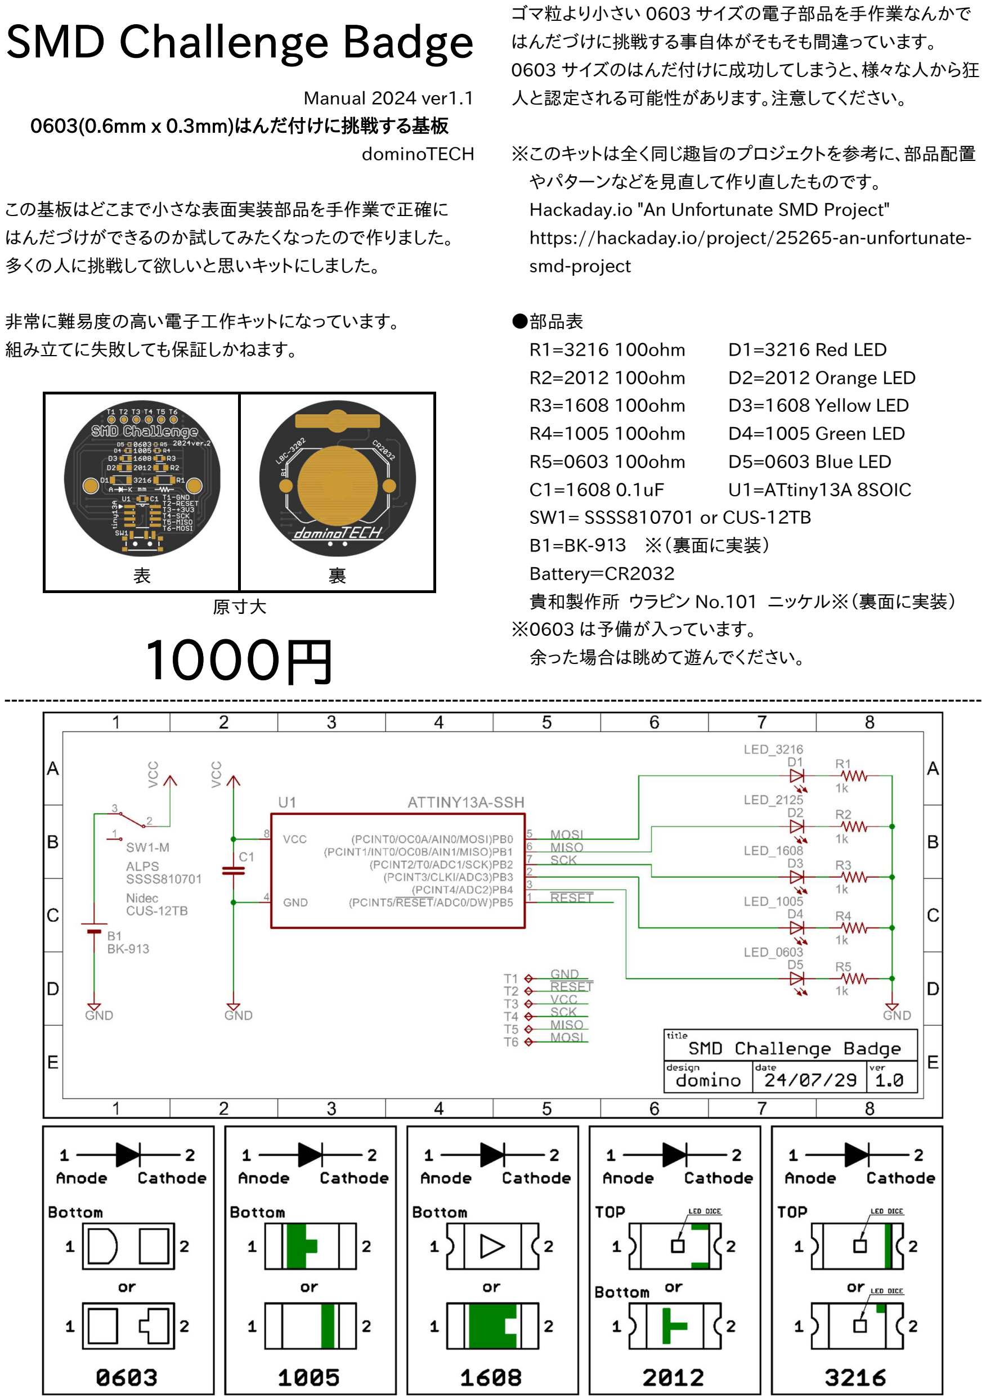
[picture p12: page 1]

Manual 2024 ver1.1
0603(0.6mm x 0.3mm)はんだ付けに挑戦する基板 dominoTECH

この基板はどこまで小さな表面実装部品を手作業で正確に はんだづけができるのか試してみたくなったので作りました。 多くの人に挑戦して欲しいと思いキットにしました。

非常に難易度の高い電子工作キットになっています。
組み立てに失敗しても保証しかねます。
表 | 裏
原寸大
１０００円

ゴマ粒より小さい 0603 サイズの電子部品を手作業なんかで はんだづけに挑戦する事自体がそもそも間違っています。 0603 サイズのはんだ付けに成功してしまうと、様々な人から狂 人と認定される可能性があります。注意してください。

※このキットは全く同じ趣旨のプロジェクトを参考に、部品配置 やパターンなどを見直して作り直したものです。
Hackaday.io "An Unfortunate SMD Project" https://hackaday.io/project/25265-an-unfortunate-smd-project

●部品表
R1=3216 100ohm | D1=3216 Red LED
R2=2012 100ohm | D2=2012 Orange LED
R3=1608 100ohm | D3=1608 Yellow LED
R4=1005 100ohm | D4=1005 Green LED
R5=0603 100ohm | D5=0603 Blue LED
C1=1608 0.1uF | U1=ATtiny13A 8SOIC
SW1= SSSS810701 or CUS-12TB
B1=BK-９１３ ※（裏面に実装）
Battery＝CR2032
貴和製作所 ウラピン No.101 ニッケル※（裏面に実装） ※0603 は予備が入っています。
余った場合は眺めて遊んでください。

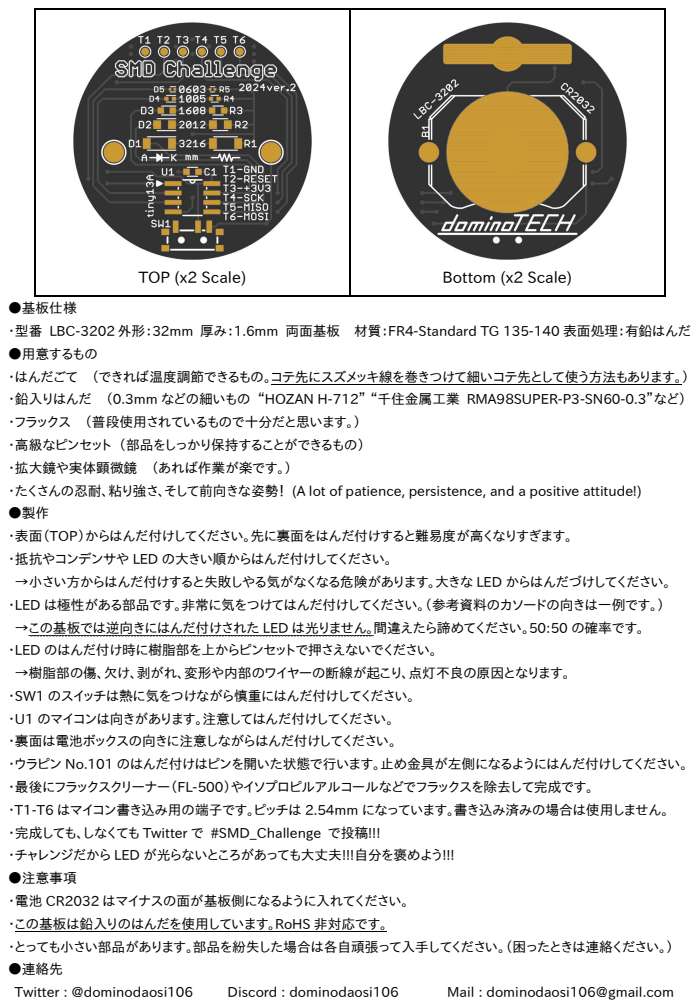
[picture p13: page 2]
TOP (x2 Scale); Bottom (x2 Scale); Twitter : @dominodaosi106; Discord : dominodaosi106; Mail : dominodaosi106@gmail.com

●基板仕様
・型番 LBC-3202 外形：32mm 厚み：1.6mm 両面基板 材質：FR4-Standard TG 135-140 表面処理：有鉛はんだ
●用意するもの
・はんだごて （できれば温度調節できるもの。コテ先にスズメッキ線を巻きつけて細いコテ先として使う方法もあります。）
・鉛入りはんだ （0.3mm などの細いもの “HOZAN H-712” “千住金属工業 RMA98SUPER-P3-SN60-0.3”など）
・フラックス （普段使用されているもので十分だと思います。）
・高級なピンセット （部品をしっかり保持することができるもの）
・拡大鏡や実体顕微鏡 （あれば作業が楽です。）
・たくさんの忍耐、粘り強さ、そして前向きな姿勢！ (A lot of patience, persistence, and a positive attitude!)
・表面（TOP）からはんだ付けしてください。先に裏面をはんだ付けすると難易度が高くなりすぎます。
・抵抗やコンデンサや LED の大きい順からはんだ付けしてください。
→小さい方からはんだ付けすると失敗しやる気がなくなる危険があります。大きな LED からはんだづけしてください。
・LED は極性がある部品です。非常に気をつけてはんだ付けしてください。（参考資料のカソードの向きは一例です。）
→この基板では逆向きにはんだ付けされた LED は光りません。間違えたら諦めてください。50:50 の確率です。
・LED のはんだ付け時に樹脂部を上からピンセットで押さえないでください。
→樹脂部の傷、欠け、剥がれ、変形や内部のワイヤーの断線が起こり、点灯不良の原因となります。
・SW1 のスイッチは熱に気をつけながら慎重にはんだ付けしてください。
・U1 のマイコンは向きがあります。注意してはんだ付けしてください。
・裏面は電池ボックスの向きに注意しながらはんだ付けしてください。
・ウラピン No.101 のはんだ付けはピンを開いた状態で行います。止め金具が左側になるようにはんだ付けしてください。
・最後にフラックスクリーナー（FL-500）やイソプロピルアルコールなどでフラックスを除去して完成です。
・T1-T6 はマイコン書き込み用の端子です。ピッチは 2.54mm になっています。書き込み済みの場合は使用しません。
・完成しても、しなくても Twitter で #SMD_Challenge で投稿!!!
・チャレンジだから LED が光らないところがあっても大丈夫!!!自分を褒めよう!!!
●注意事項
・電池 CR2032 はマイナスの面が基板側になるように入れてください。
・この基板は鉛入りのはんだを使用しています。RoHS 非対応です。
・とっても小さい部品があります。部品を紛失した場合は各自頑張って入手してください。（困ったときは連絡ください。）
●連絡先

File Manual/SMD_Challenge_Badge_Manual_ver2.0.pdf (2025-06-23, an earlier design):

# SMD Challenge Badge

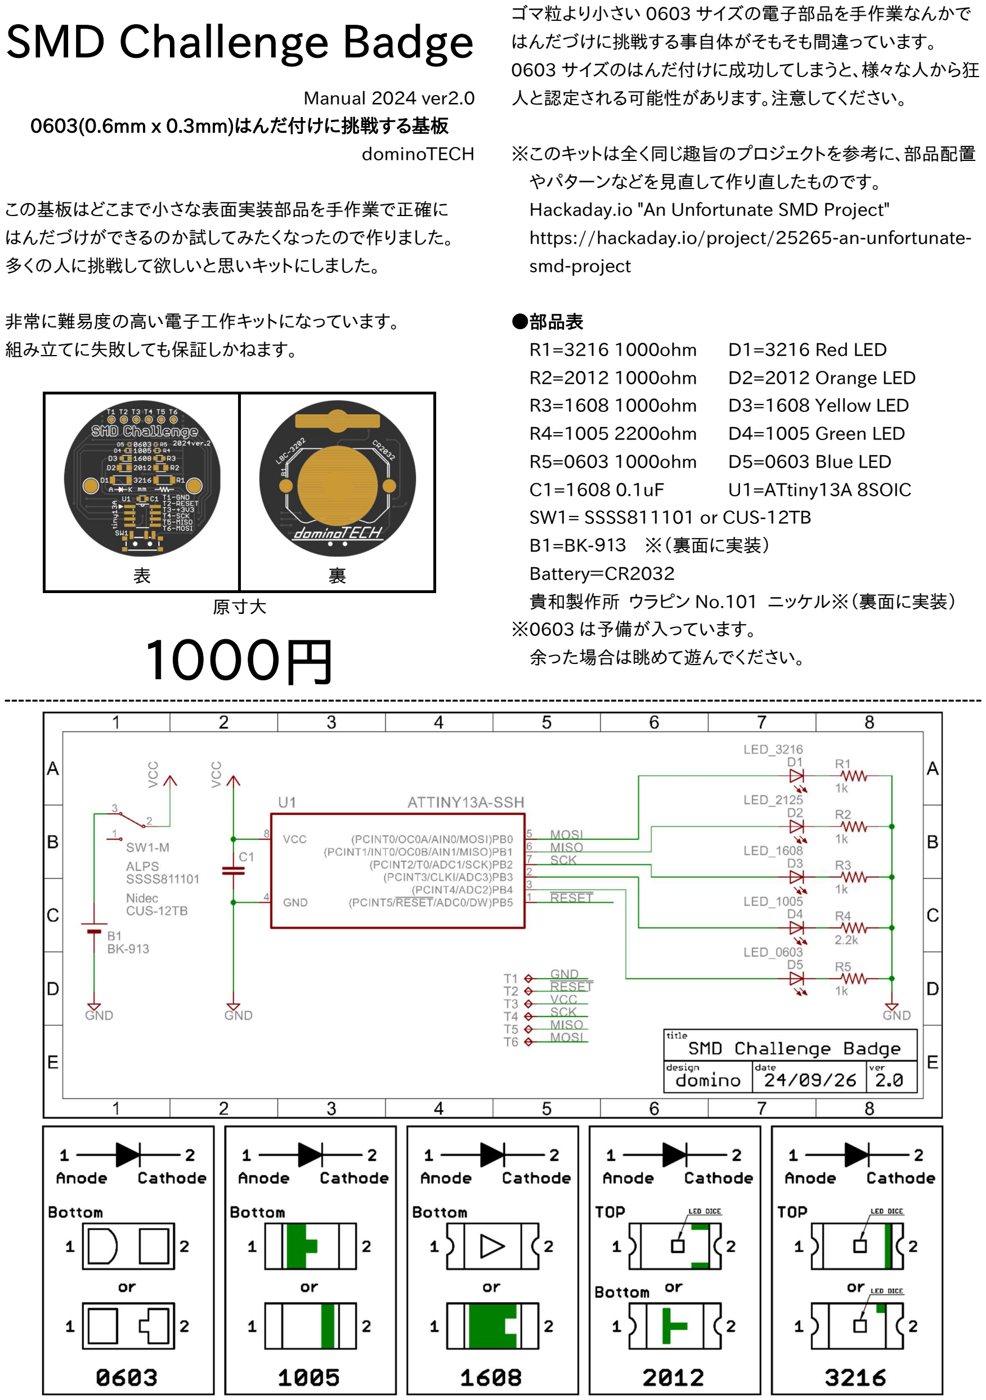
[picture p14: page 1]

Manual 2024 ver2.0
0603(0.6mm x 0.3mm)はんだ付けに挑戦する基板 dominoTECH

この基板はどこまで小さな表面実装部品を手作業で正確に はんだづけができるのか試してみたくなったので作りました。 多くの人に挑戦して欲しいと思いキットにしました。

非常に難易度の高い電子工作キットになっています。
組み立てに失敗しても保証しかねます。
表 | 裏
原寸大
１０００円

ゴマ粒より小さい 0603 サイズの電子部品を手作業なんかで はんだづけに挑戦する事自体がそもそも間違っています。 0603 サイズのはんだ付けに成功してしまうと、様々な人から狂 人と認定される可能性があります。注意してください。

※このキットは全く同じ趣旨のプロジェクトを参考に、部品配置 やパターンなどを見直して作り直したものです。
Hackaday.io "An Unfortunate SMD Project" https://hackaday.io/project/25265-an-unfortunate-smd-project

●部品表
R1=3216 1000ohm | D1=3216 Red LED
R2=2012 1000ohm | D2=2012 Orange LED
R3=1608 1000ohm | D3=1608 Yellow LED
R4=1005 2200ohm | D4=1005 Green LED
R5=0603 1000ohm | D5=0603 Blue LED
C1=1608 0.1uF | U1=ATtiny13A 8SOIC
SW1= SSSS811101 or CUS-12TB
B1=BK-９１３ ※（裏面に実装）
Battery＝CR2032
貴和製作所 ウラピン No.101 ニッケル※（裏面に実装） ※0603 は予備が入っています。
余った場合は眺めて遊んでください。

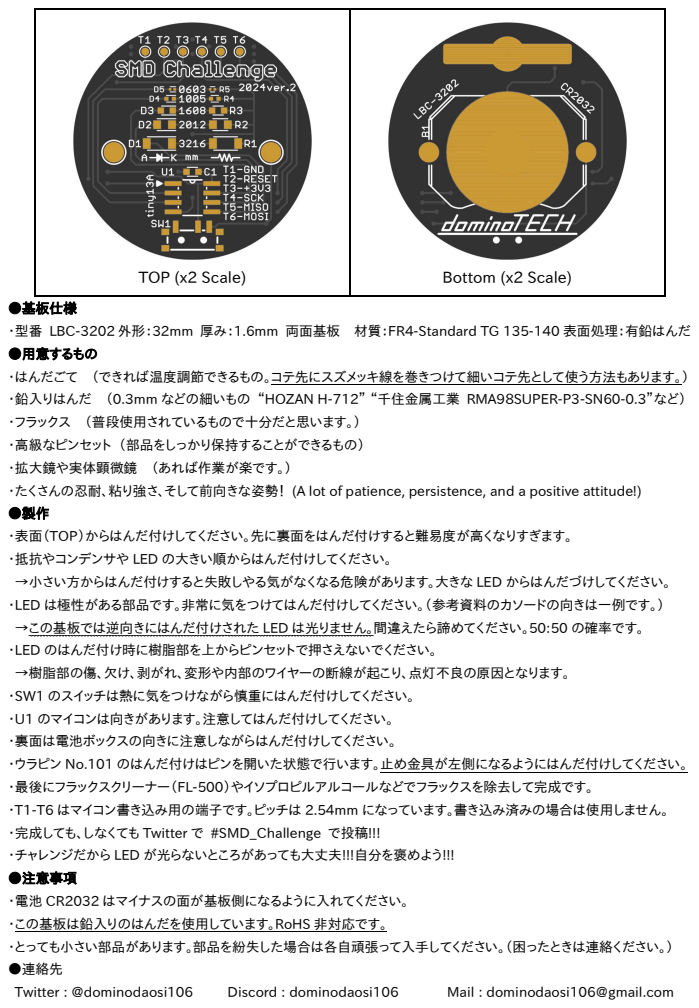
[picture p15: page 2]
TOP (x2 Scale); Bottom (x2 Scale); Twitter : @dominodaosi106; Discord : dominodaosi106; Mail : dominodaosi106@gmail.com

●基板仕様
・型番 LBC-3202 外形：32mm 厚み：1.6mm 両面基板 材質：FR4-Standard TG 135-140 表面処理：有鉛はんだ
●用意するもの
・はんだごて （できれば温度調節できるもの。コテ先にスズメッキ線を巻きつけて細いコテ先として使う方法もあります。）
・鉛入りはんだ （0.3mm などの細いもの “HOZAN H-712” “千住金属工業 RMA98SUPER-P3-SN60-0.3”など）
・フラックス （普段使用されているもので十分だと思います。）
・高級なピンセット （部品をしっかり保持することができるもの）
・拡大鏡や実体顕微鏡 （あれば作業が楽です。）
・たくさんの忍耐、粘り強さ、そして前向きな姿勢！ (A lot of patience, persistence, and a positive attitude!)
・表面（TOP）からはんだ付けしてください。先に裏面をはんだ付けすると難易度が高くなりすぎます。
・抵抗やコンデンサや LED の大きい順からはんだ付けしてください。
→小さい方からはんだ付けすると失敗しやる気がなくなる危険があります。大きな LED からはんだづけしてください。
・LED は極性がある部品です。非常に気をつけてはんだ付けしてください。（参考資料のカソードの向きは一例です。）
→この基板では逆向きにはんだ付けされた LED は光りません。間違えたら諦めてください。50:50 の確率です。
・LED のはんだ付け時に樹脂部を上からピンセットで押さえないでください。
→樹脂部の傷、欠け、剥がれ、変形や内部のワイヤーの断線が起こり、点灯不良の原因となります。
・SW1 のスイッチは熱に気をつけながら慎重にはんだ付けしてください。
・U1 のマイコンは向きがあります。注意してはんだ付けしてください。
・裏面は電池ボックスの向きに注意しながらはんだ付けしてください。
・ウラピン No.101 のはんだ付けはピンを開いた状態で行います。止め金具が左側になるようにはんだ付けしてください。
・最後にフラックスクリーナー（FL-500）やイソプロピルアルコールなどでフラックスを除去して完成です。
・T1-T6 はマイコン書き込み用の端子です。ピッチは 2.54mm になっています。書き込み済みの場合は使用しません。
・完成しても、しなくても Twitter で #SMD_Challenge で投稿!!!
・チャレンジだから LED が光らないところがあっても大丈夫!!!自分を褒めよう!!!
●注意事項
・電池 CR2032 はマイナスの面が基板側になるように入れてください。
・この基板は鉛入りのはんだを使用しています。RoHS 非対応です。
・とっても小さい部品があります。部品を紛失した場合は各自頑張って入手してください。（困ったときは連絡ください。）
●連絡先

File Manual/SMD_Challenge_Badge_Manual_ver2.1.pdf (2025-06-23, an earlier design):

# SMD Challenge Badge

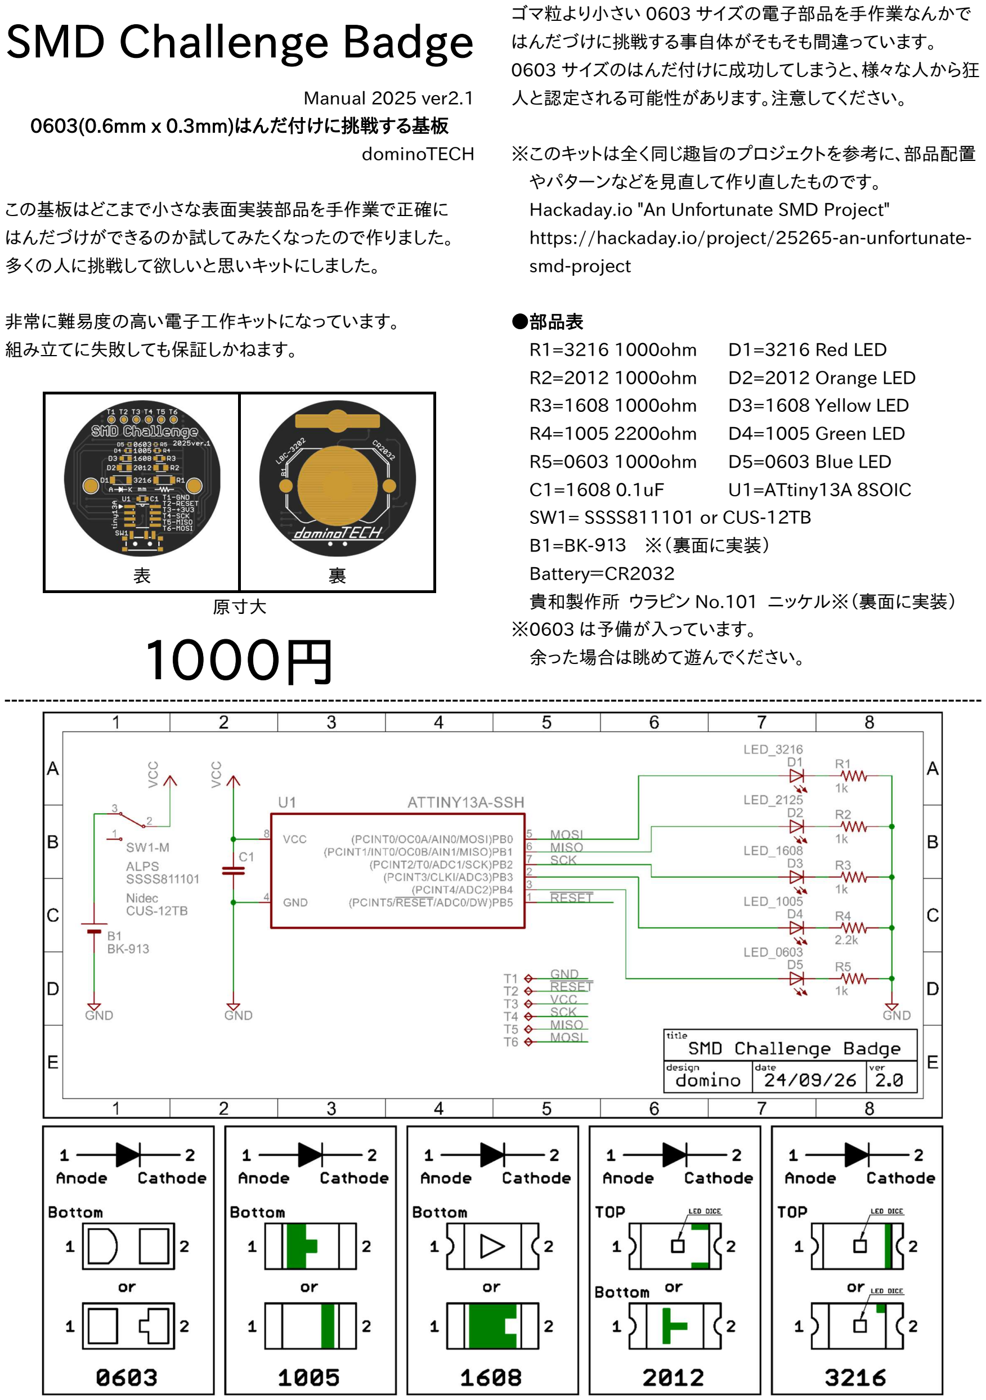
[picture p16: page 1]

Manual 2025 ver2.1
0603(0.6mm x 0.3mm)はんだ付けに挑戦する基板 dominoTECH

この基板はどこまで小さな表面実装部品を手作業で正確に はんだづけができるのか試してみたくなったので作りました。 多くの人に挑戦して欲しいと思いキットにしました。

非常に難易度の高い電子工作キットになっています。
組み立てに失敗しても保証しかねます。
表 | 裏
原寸大
１０００円

ゴマ粒より小さい 0603 サイズの電子部品を手作業なんかで はんだづけに挑戦する事自体がそもそも間違っています。 0603 サイズのはんだ付けに成功してしまうと、様々な人から狂 人と認定される可能性があります。注意してください。

※このキットは全く同じ趣旨のプロジェクトを参考に、部品配置 やパターンなどを見直して作り直したものです。
Hackaday.io "An Unfortunate SMD Project" https://hackaday.io/project/25265-an-unfortunate-smd-project

●部品表
R1=3216 1000ohm | D1=3216 Red LED
R2=2012 1000ohm | D2=2012 Orange LED
R3=1608 1000ohm | D3=1608 Yellow LED
R4=1005 2200ohm | D4=1005 Green LED
R5=0603 1000ohm | D5=0603 Blue LED
C1=1608 0.1uF | U1=ATtiny13A 8SOIC
SW1= SSSS811101 or CUS-12TB
B1=BK-９１３ ※（裏面に実装）
Battery＝CR2032
貴和製作所 ウラピン No.101 ニッケル※（裏面に実装） ※0603 は予備が入っています。
余った場合は眺めて遊んでください。

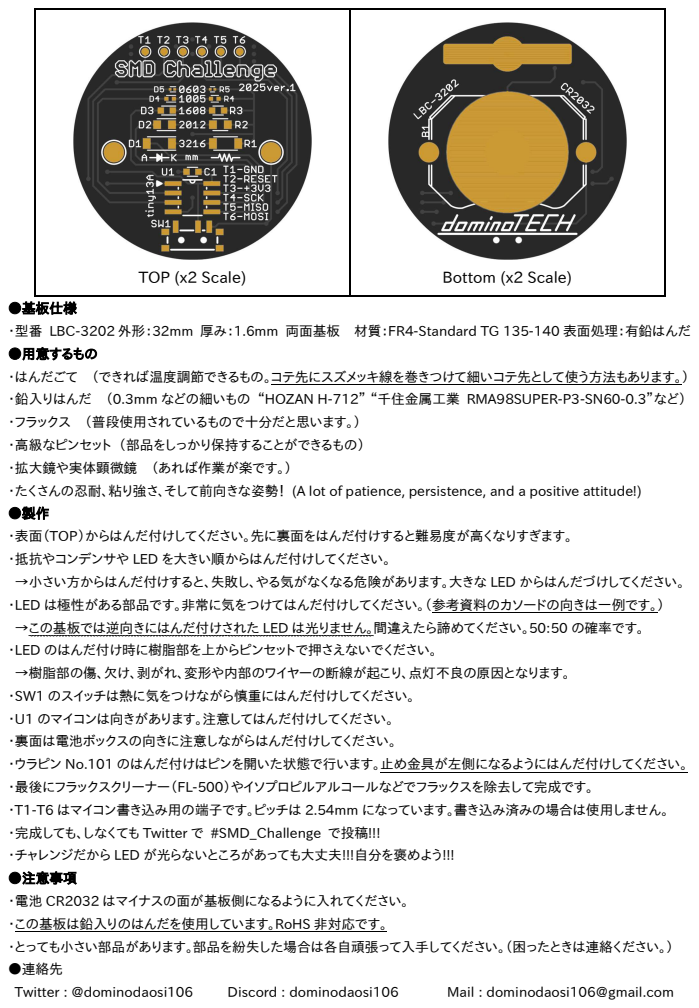
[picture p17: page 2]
TOP (x2 Scale); Bottom (x2 Scale); Twitter : @dominodaosi106; Discord : dominodaosi106; Mail : dominodaosi106@gmail.com

●基板仕様
・型番 LBC-3202 外形：32mm 厚み：1.6mm 両面基板 材質：FR4-Standard TG 135-140 表面処理：有鉛はんだ
●用意するもの
・はんだごて （できれば温度調節できるもの。コテ先にスズメッキ線を巻きつけて細いコテ先として使う方法もあります。）
・鉛入りはんだ （0.3mm などの細いもの “HOZAN H-712” “千住金属工業 RMA98SUPER-P3-SN60-0.3”など）
・フラックス （普段使用されているもので十分だと思います。）
・高級なピンセット （部品をしっかり保持することができるもの）
・拡大鏡や実体顕微鏡 （あれば作業が楽です。）
・たくさんの忍耐、粘り強さ、そして前向きな姿勢！ (A lot of patience, persistence, and a positive attitude!)
・表面（TOP）からはんだ付けしてください。先に裏面をはんだ付けすると難易度が高くなりすぎます。
・抵抗やコンデンサや LED を大きい順からはんだ付けしてください。
→小さい方からはんだ付けすると、失敗し、やる気がなくなる危険があります。大きな LED からはんだづけしてください。
・LED は極性がある部品です。非常に気をつけてはんだ付けしてください。（参考資料のカソードの向きは一例です。）
→この基板では逆向きにはんだ付けされた LED は光りません。間違えたら諦めてください。50:50 の確率です。
・LED のはんだ付け時に樹脂部を上からピンセットで押さえないでください。
→樹脂部の傷、欠け、剥がれ、変形や内部のワイヤーの断線が起こり、点灯不良の原因となります。
・SW1 のスイッチは熱に気をつけながら慎重にはんだ付けしてください。
・U1 のマイコンは向きがあります。注意してはんだ付けしてください。
・裏面は電池ボックスの向きに注意しながらはんだ付けしてください。
・ウラピン No.101 のはんだ付けはピンを開いた状態で行います。止め金具が左側になるようにはんだ付けしてください。
・最後にフラックスクリーナー（FL-500）やイソプロピルアルコールなどでフラックスを除去して完成です。
・T1-T6 はマイコン書き込み用の端子です。ピッチは 2.54mm になっています。書き込み済みの場合は使用しません。
・完成しても、しなくても Twitter で #SMD_Challenge で投稿!!!
・チャレンジだから LED が光らないところがあっても大丈夫!!!自分を褒めよう!!!
●注意事項
・電池 CR2032 はマイナスの面が基板側になるように入れてください。
・この基板は鉛入りのはんだを使用しています。RoHS 非対応です。
・とっても小さい部品があります。部品を紛失した場合は各自頑張って入手してください。（困ったときは連絡ください。）
●連絡先

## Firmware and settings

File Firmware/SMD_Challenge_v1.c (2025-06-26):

/*
 *SMD Challenge Badge ATtiny13A 32mm 
 *製作 dominoTECH EqUret
 *製作年 20240809
 */

/*
 * SMD_Challenge Firmware
 * Based on: Attiny85Challenge by aspro648 (https://github.com/aspro648/KiCad/tree/master/projects/Attiny/Attiny85Challenge)
 * License: Creative Commons Attribution-ShareAlike 3.0 United States (CC BY-SA 3.0 US)
 * https://creativecommons.org/licenses/by-sa/3.0/us/
 */

#include<avr/io.h>
#include<util/delay.h>

const uint8_t LED_CTRL_REG[] = {0x01,0x02,0x04,0x08,0x10};


void onled (int index)
    {
    PORTB = LED_CTRL_REG[index];
    }

int main(void){
	DDRB  =0b00011111;	// ポートB 01234出力
	PORTB = 0x00;  // ポートB初期化

    unsigned char x;

    while(1){		//メインループ
        for (x=0;x < 5; x++){
        onled(x);
        _delay_ms(200);
        PORTB = 0;
        _delay_us(100);
        }
        for (x=0;x < 3; x++){
        onled(3-x);
        _delay_ms(200);
        PORTB = 0;
        _delay_ms(1);
        }
    }
}

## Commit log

2025-06-25 Gerber up
    [32mm.GBL, 32mm.GBO, 32mm.GBS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]
2025-06-26 COMPLETERS 追加
2025-08-04 STL up
    [40mm_round_cap.stl, 40mm_round_case.stl]
